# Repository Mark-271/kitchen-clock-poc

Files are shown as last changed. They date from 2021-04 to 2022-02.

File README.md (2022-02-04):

# Kitchen clock
This is the project of the kitchen clock with the following functions:
- date
- alarm
- clock
- 24 hour time format
- thermometer
## Breadboard connection
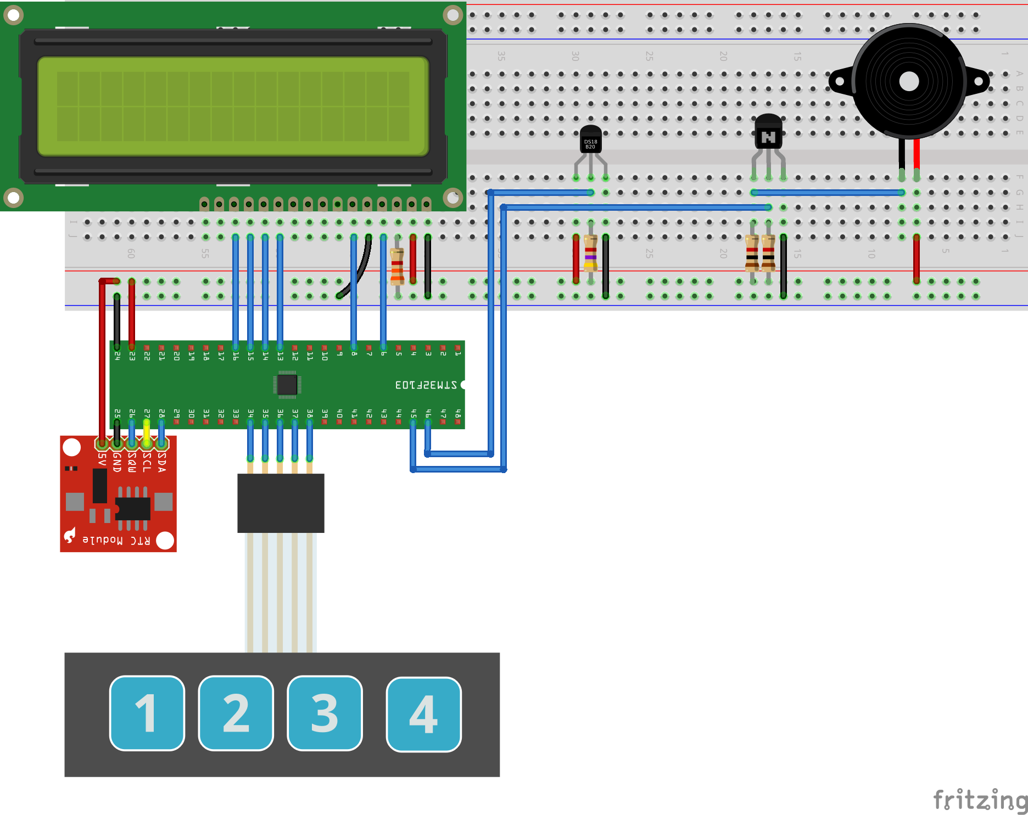
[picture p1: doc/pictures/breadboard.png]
bb

## Electrical wiring diagram
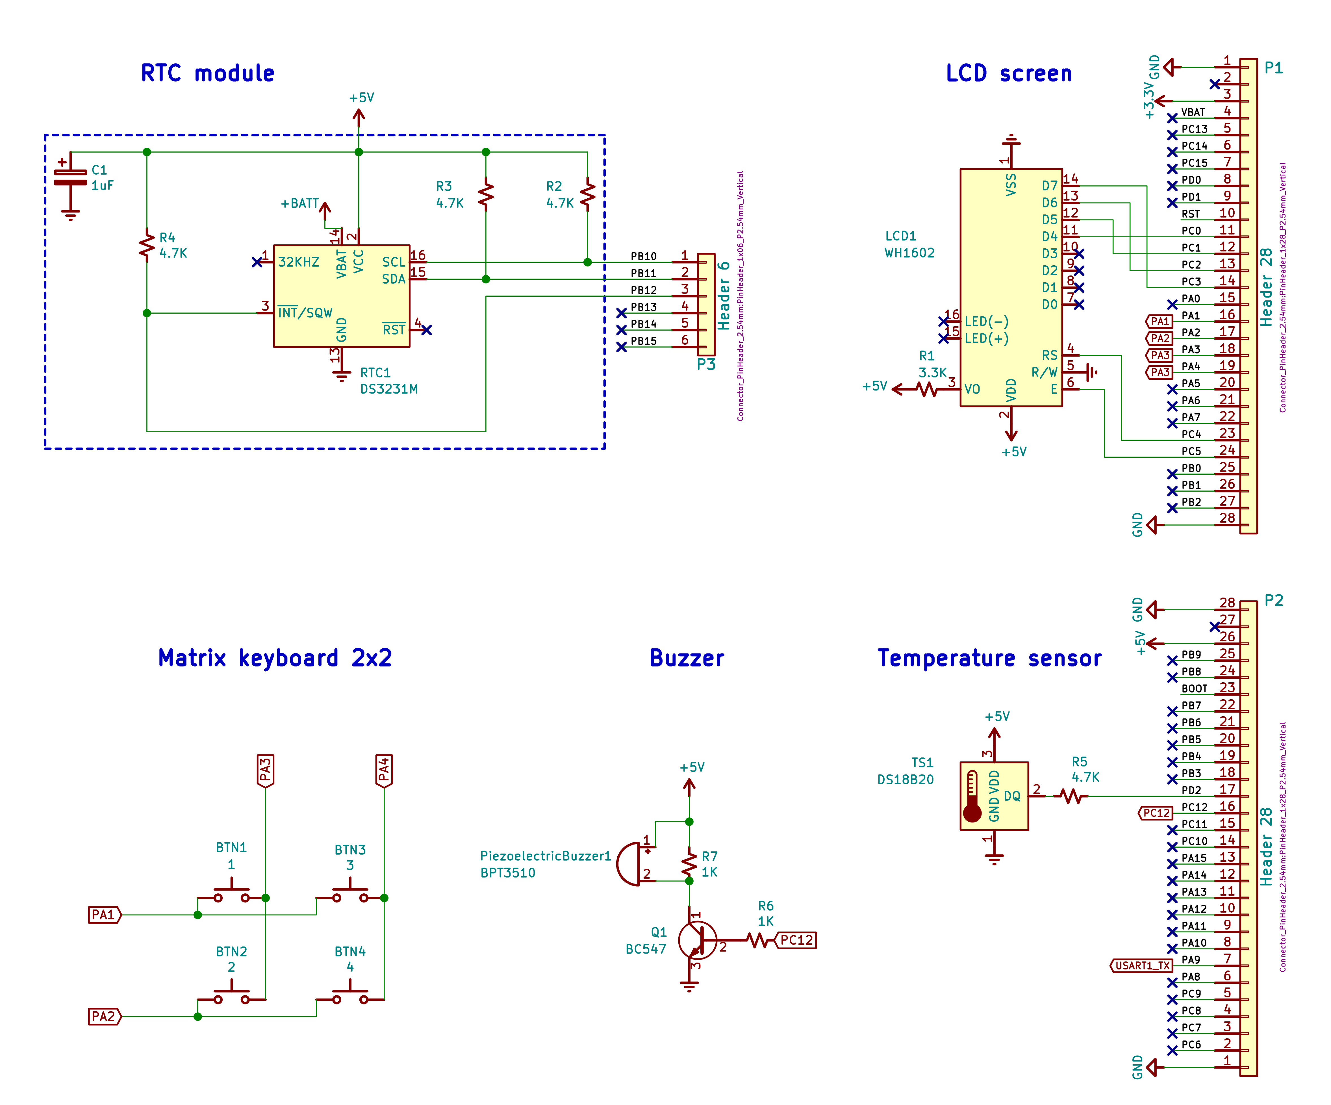
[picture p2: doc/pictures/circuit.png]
scheme

## Used electronic components
- STM32VLDISCOVERY board with the STM32F100RB MCU
- digital thermometer DS18B20
- LCD screen WH1602
- matrix keyboard 2x2
- RTC module DS3231
- piezoelectric buzzer
- resistors:
  - 1 kohm *(x2)*
  - 4.7 kohm *(x1)*
  - 3.3 kohm *(x1)*
- NPN transistor BC547 *(x1)*
- breadboard
- jumper wires
## Building and installing
### Prerequisites
Building requires libopencm3 and an arm-none-eabi toolchain.
The build must be tuned with limited number of parameters in Makefile,
by specifying them as environment variables, for example:
```
export PATH=/opt/gcc-arm-none-eabi-9-2020-q2-update/bin:$PATH
export CROSS_COMPILE=arm-none-eabi-
export OPENCM3_DIR=$HOME/repos/libopencm3
```
- `CROSS_COMPILE` contains `arm-none-eabi-` prefix
- `OPENCM3_DIR` contains path to root directory of
[libopencm3](https://github.com/libopencm3/libopencm3) source tree (must
be built)
### Serial console
Serial communication (used in the project, for example, for debug) is
performed via `minicom` through RS-232 adapter.
*PA9* as the default *USART1_TX* pin is used on the STM32VLDISCOVERY board.

UART configuration:
```
115200 8N1
No flowcontrol
```
### Building
```
$ make
```
### Flashing
For flashing `st-flash` utility is used.
```
$ make flash
```
## Author
**Mark Sungurov <mark.sungurov@gmail.com>**
## License
This project is licensed under the GPLv3.

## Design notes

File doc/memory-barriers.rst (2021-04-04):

Memory barriers
===============

(borrowed from Linux kernel memory-barriers.txt)

Compiler barrier
----------------

The Linux kernel has an explicit compiler barrier function that prevents the
compiler from moving the memory accesses either side of it to the other side::

    barrier();

This is a general barrier -- there are no read-read or write-write
variants of ``barrier()``.  However, ``READ_ONCE()`` and ``WRITE_ONCE()`` can be
thought of as weak forms of ``barrier()`` that affect only the specific
accesses flagged by the ``READ_ONCE()`` or ``WRITE_ONCE()``.

The ``barrier()`` function has the following effects:

* Prevents the compiler from reordering accesses following the
  ``barrier()`` to precede any accesses preceding the ``barrier()``.
  One example use for this property is to ease communication between
  interrupt-handler code and the code that was interrupted.
* Within a loop, forces the compiler to load the variables used
  in that loop's conditional on each pass through that loop.

The ``READ_ONCE()`` and ``WRITE_ONCE()`` functions can prevent any number of
optimizations that, while perfectly safe in single-threaded code, can
be fatal in concurrent code.  Here are some examples of these sorts
of optimizations:

* The compiler is within its rights to reorder loads and stores
  to the same variable, and in some cases, the CPU is within its
  rights to reorder loads to the same variable.  This means that
  the following code:

  .. code-block:: c

      a[0] = x;
      a[1] = x;

  Might result in an older value of x stored in a[1] than in a[0].
  Prevent both the compiler and the CPU from doing this as follows:

  .. code-block:: c

      a[0] = READ_ONCE(x);
      a[1] = READ_ONCE(x);

  In short, ``READ_ONCE()`` and ``WRITE_ONCE()`` provide cache coherence for
  accesses from multiple CPUs to a single variable.

* The compiler is within its rights to merge successive loads from
  the same variable.  Such merging can cause the compiler to "optimize"
  the following code:

  .. code-block:: c

      while (tmp = a)
      do_something_with(tmp);

  into the following code, which, although in some sense legitimate
  for single-threaded code, is almost certainly not what the developer
  intended:

  .. code-block:: c

      if (tmp = a)
          for (;;)
              do_something_with(tmp);

  Use ``READ_ONCE()`` to prevent the compiler from doing this to you:

  .. code-block:: c

      while (tmp = READ_ONCE(a))
          do_something_with(tmp);

* The compiler is within its rights to reload a variable, for example,
  in cases where high register pressure prevents the compiler from
  keeping all data of interest in registers.  The compiler might
  therefore optimize the variable ``tmp`` out of our previous example:

  .. code-block:: c

      while (tmp = a)
          do_something_with(tmp);

  This could result in the following code, which is perfectly safe in
  single-threaded code, but can be fatal in concurrent code:

  .. code-block:: c

      while (a)
          do_something_with(a);

  For example, the optimized version of this code could result in
  passing a zero to ``do_something_with()`` in the case where the variable
  a was modified by some other CPU between the ``while`` statement and
  the call to ``do_something_with()``.

  Again, use ``READ_ONCE()`` to prevent the compiler from doing this:

  .. code-block:: c

      while (tmp = READ_ONCE(a))
          do_something_with(tmp);

  Note that if the compiler runs short of registers, it might save
  ``tmp`` onto the stack.  The overhead of this saving and later restoring
  is why compilers reload variables.  Doing so is perfectly safe for
  single-threaded code, so you need to tell the compiler about cases
  where it is not safe.

* The compiler is within its rights to omit a load entirely if it knows
  what the value will be.  For example, if the compiler can prove that
  the value of variable ``a`` is always zero, it can optimize this code:

  .. code-block:: c

      while (tmp = a)
          do_something_with(tmp);

  Into this:

  .. code-block:: c

      do { } while (0);

  This transformation is a win for single-threaded code because it
  gets rid of a load and a branch.  The problem is that the compiler
  will carry out its proof assuming that the current CPU is the only
  one updating variable ``a``.  If variable ``a`` is shared, then the
  compiler's proof will be erroneous.  Use ``READ_ONCE()`` to tell the
  compiler that it doesn't know as much as it thinks it does:

  .. code-block:: c

      while (tmp = READ_ONCE(a))
          do_something_with(tmp);

  But please note that the compiler is also closely watching what you
  do with the value after the ``READ_ONCE()``.  For example, suppose you
  do the following and ``MAX`` is a preprocessor macro with the value 1:

  .. code-block:: c

      while ((tmp = READ_ONCE(a)) % MAX)
          do_something_with(tmp);

  Then the compiler knows that the result of the ``%`` operator applied
  to ``MAX`` will always be zero, again allowing the compiler to optimize
  the code into near-nonexistence.  (It will still load from the
  variable ``a``.)

* Similarly, the compiler is within its rights to omit a store entirely
  if it knows that the variable already has the value being stored.
  Again, the compiler assumes that the current CPU is the only one
  storing into the variable, which can cause the compiler to do the
  wrong thing for shared variables.  For example, suppose you have
  the following:

  .. code-block:: c

      a = 0;
      ... Code that does not store to variable a ...
      a = 0;

  The compiler sees that the value of variable ``a`` is already zero, so
  it might well omit the second store.  This would come as a fatal
  surprise if some other CPU might have stored to variable ``a`` in the
  meantime.

  Use ``WRITE_ONCE()`` to prevent the compiler from making this sort of
  wrong guess:

  .. code-block:: c

      WRITE_ONCE(a, 0);
      ... Code that does not store to variable a ...
      WRITE_ONCE(a, 0);

* The compiler is within its rights to reorder memory accesses unless
  you tell it not to.  For example, consider the following interaction
  between process-level code and an interrupt handler:

  .. code-block:: c

      void process_level(void)
      {
          msg = get_message();
          flag = true;
      }

       void interrupt_handler(void)
       {
           if (flag)
               process_message(msg);
       }

  There is nothing to prevent the compiler from transforming
  ``process_level()`` to the following, in fact, this might well be a
  win for single-threaded code:

  .. code-block:: c

      void process_level(void)
      {
          flag = true;
          msg = get_message();
      }

  If the interrupt occurs between these two statement, then
  ``interrupt_handler()`` might be passed a garbled ``msg``.  Use
  ``WRITE_ONCE()`` to prevent this as follows:

  .. code-block:: c

      void process_level(void)
      {
          WRITE_ONCE(msg, get_message());
          WRITE_ONCE(flag, true);
      }

      void interrupt_handler(void)
      {
          if (READ_ONCE(flag))
              process_message(READ_ONCE(msg));
      }

  Note that the ``READ_ONCE()`` and ``WRITE_ONCE()`` wrappers in
  ``interrupt_handler()`` are needed if this interrupt handler can itself
  be interrupted by something that also accesses ``flag`` and ``msg``,
  for example, a nested interrupt or an NMI.  Otherwise, ``READ_ONCE()``
  and ``WRITE_ONCE()`` are not needed in ``interrupt_handler()`` other than
  for documentation purposes.  (Note also that nested interrupts
  do not typically occur in modern Linux kernels, in fact, if an
  interrupt handler returns with interrupts enabled, you will get a
  ``WARN_ONCE()`` splat.)

  You should assume that the compiler can move ``READ_ONCE()`` and
  ``WRITE_ONCE()`` past code not containing ``READ_ONCE()``, ``WRITE_ONCE()``,
  ``barrier()``, or similar primitives.

  This effect could also be achieved using ``barrier()``, but ``READ_ONCE()``
  and ``WRITE_ONCE()`` are more selective:  With ``READ_ONCE()`` and
  ``WRITE_ONCE()``, the compiler need only forget the contents of the
  indicated memory locations, while with ``barrier()`` the compiler must
  discard the value of all memory locations that it has currented
  cached in any machine registers.  Of course, the compiler must also
  respect the order in which the ``READ_ONCE()``-s and ``WRITE_ONCE()``-s
  occur, though the CPU of course need not do so.

* The compiler is within its rights to invent stores to a variable,
  as in the following example:

  .. code-block:: c

      if (a)
          b = a;
      else
          b = 42;

  The compiler might save a branch by optimizing this as follows:

  .. code-block:: c

      b = 42;
      if (a)
          b = a;

  In single-threaded code, this is not only safe, but also saves
  a branch.  Unfortunately, in concurrent code, this optimization
  could cause some other CPU to see a spurious value of 42 -- even
  if variable ``a`` was never zero -- when loading variable ``b``.
  Use ``WRITE_ONCE()`` to prevent this as follows:

  .. code-block:: c

      if (a)
          WRITE_ONCE(b, a);
      else
          WRITE_ONCE(b, 42);

  The compiler can also invent loads.  These are usually less
  damaging, but they can result in cache-line bouncing and thus in
  poor performance and scalability.  Use ``READ_ONCE()`` to prevent
  invented loads.

* For aligned memory locations whose size allows them to be accessed
  with a single memory-reference instruction, prevents "load tearing"
  and "store tearing", in which a single large access is replaced by
  multiple smaller accesses.  For example, given an architecture having
  16-bit store instructions with 7-bit immediate fields, the compiler
  might be tempted to use two 16-bit store-immediate instructions to
  implement the following 32-bit store:

  .. code-block:: c

      p = 0x00010002;

  Please note that GCC really does use this sort of optimization,
  which is not surprising given that it would likely take more
  than two instructions to build the constant and then store it.
  This optimization can therefore be a win in single-threaded code.
  In fact, a recent bug (since fixed) caused GCC to incorrectly use
  this optimization in a volatile store.  In the absence of such bugs,
  use of ``WRITE_ONCE()`` prevents store tearing in the following example:

  .. code-block:: c

      WRITE_ONCE(p, 0x00010002);

  Use of packed structures can also result in load and store tearing,
  as in this example:

  .. code-block:: c

      struct __attribute__((__packed__)) foo {
          short a;
          int b;
          short c;
      };
      struct foo foo1, foo2;
      ...

      foo2.a = foo1.a;
      foo2.b = foo1.b;
      foo2.c = foo1.c;

  Because there are no ``READ_ONCE()`` or ``WRITE_ONCE()`` wrappers and no
  ``volatile`` markings, the compiler would be well within its rights to
  implement these three assignment statements as a pair of 32-bit
  loads followed by a pair of 32-bit stores.  This would result in
  load tearing on ``foo1.b`` and store tearing on ``foo2.b``.  ``READ_ONCE()``
  and ``WRITE_ONCE()`` again prevent tearing in this example:

  .. code-block:: c

      foo2.a = foo1.a;
      WRITE_ONCE(foo2.b, READ_ONCE(foo1.b));
      foo2.c = foo1.c;

All that aside, it is never necessary to use ``READ_ONCE()`` and
``WRITE_ONCE()`` on a variable that has been marked ``volatile``.  For example,
because ``jiffies`` is marked ``volatile``, it is never necessary to
say ``READ_ONCE(jiffies)``.  The reason for this is that ``READ_ONCE()`` and
``WRITE_ONCE()`` are implemented as ``volatile`` casts, which has no effect when
its argument is already marked ``volatile``.

Please note that these compiler barriers have no direct effect on the CPU,
which may then reorder things however it wishes (but Cortex-M doesn't do
reordering).

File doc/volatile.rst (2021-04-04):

Do not use "volatile" modifier
==============================

:Author: Sam Protsenko

``volatile`` keyword purpose is to turn off the compiler optimizations for
caching the variable in the register. Very rarely its usage is justified. This
document discusses why its usage should be avoided at all in the firmware code.
It's also discouraged to use ``volatile`` in Linux kernel, see [1]_ for details.

As discussed below, ``volatile`` shouldn't be used at all. Using provided in
the firmware sync API (like ``READ_ONCE()``, ``WRITE_ONCE()``,
``enter_critical()``, ``exit_critical()`` and ``barrier()``) and libopencm3 API
for accessing the memory-mapped registers (like ``MMIO32()``) takes care of
disabling optimizations for us, so that we can avoid using ``volatile`` at all.

Summary
-------

Here is a short cheat sheet on when to use which API:

 * **Never** use ``volatile`` keyword explicitly in your code
 * Use existing API to access hardware registers (like ``MMIO32()``)
 * Use ``READ_ONCE()`` (in mainline code): for accessing global variables that
   change in ISR (to avoid compiler optimizations)
 * Use ``WRITE_ONCE()`` (in ISR code): when changing global variables
   (pairing it with ``READ_ONCE()`` helps compiler to understand variable usage)
 * Use local non-volatile variable to keep ``READ_ONCE()`` result
   (to avoid under-optimization)
 * Use critical sections ( ``enter_critical()``, ``exit_critical()`` ) to
   perform non-atomic operations (Read-Modify-Write, multi-word variable access,
   unaligned access, etc) in mutual-exclusive manner
 * There is no need to use ``READ_ONCE()`` if you are already inside of
   critical section
 * If you need atomic bit operations (bit-wise RMW per once CPU instruction),
   consider using bit-banding mechanism (see ``BBIO_SRAM()`` and
   ``BBIO_PERIPH()`` API in libopencm3)
 * Use ``barrier()`` to avoid compiler reordering of load/store instructions
   (e.g. to keep the order of two sequntial atomic operations)
 * For implementing delay loops: use either ``READ_ONCE()`` for checking
   the condition or just add ``barrier()`` inside the loop. Even better idea is
   to use existing API like ``mdelay()`` or software timers API to implement
   non-blocking sleep.

Details are discussed further.

Using ``volatile`` for ISR modifiable variable
----------------------------------------------

In Embedded world the ``volatile`` is often used for global variables being
modified from ISR. Compiler can't see the access to that variable from ISR, as
ISR is not executed from any other function. Here is an example:

.. code-block:: c

    static int a;

    int main(void)
    {
        while (a == 0) { }
    }

    void some_isr(void)
    {
        a++;
    }

In this case a compiler indeed throws the ``a == 0`` check away, which leads to
infinite loop. And a programmer might have a temptation to add ``volatile``
modifier to ``a`` variable declaration, like this:

.. code-block:: c

    static volatile int a;

    int main(void)
    {
        while (a == 0) { }
    }

    void some_isr(void)
    {
        a++;
    }

It disables optimizations for ``a`` variable, so compiler will produce correct
binary. But it's not recommended to use this approach because:

  * using ``volatile`` in more elaborate cases is very inefficient, as it
    disables optimizations for all accesses to the variable
  * when calling some functions on that variable, functions must also take
    ``volatile`` parameters, which gets ugly very fast; think about implementing
    queue struct and functions and using it on ``volatile`` variable
  * using ``volatile`` doesn't fix reordering of memory operations (which can be
    done by compiler and CPU); though it is guaranteed that accesses to
    ``volatile`` variable will be ordered, compiler still can generate
    out-of-order instructions between ``volatile`` variable and other variables.
    And of course the processor is free to do any reordering anyway.
  * using ``volatile`` doesn't make variable operations atomic

The C Standard mentions::

    If it is necessary to access a nonvolatile object using volatile semantics,
    the technique is to cast the address of the object to the appropriate
    pointer-to-qualified type, then dereference that pointer.

So here is a better way to disable optimizations using ``volatile`` "in place":

.. code-block:: c

    static int a;

    int main(void)
    {
        while (*(volatile int *)&a == 0) { }
    }

    void some_isr(void)
    {
        a++;
    }

Alternatively, you could place a ``barrier()`` call in the loop.

Even better to do the same using ``READ_ONCE()`` / ``WRITE_ONCE()`` macros
(borrowed from kernel), as compiler will order all memory accesses to ``a``
variable (as both accesses are now marked as ``volatile``):

.. code-block:: c

    static int a;

    int main(void)
    {
        while (READ_ONCE(a) == 0) { }
    }

    void some_isr(void)
    {
        WRITE_ONCE(a, a + 1);
    }

.. warning::

    ``READ_ONCE()`` OR ``WRITE_ONCE()`` DO NOT IMPLY A BARRIER!

So if you want to suppress compiler reordering between accesses to ``a`` and
other variables, additional ``barrier()`` call should be used. But be aware of
possible use-case implications! Refer to [2]_ for further details.

If there is a need to do RMW operation (which is not atomic), one should disable
interrupts to achieve the mutual exclusive behavior. ``enter_critical()`` /
``exit_critical()`` API can be used for this. There is an important thing about
calling external functions::

    Compiler is not allowed to reorder code across external function calls.

Mentioned critical section functions are actually macros, but they incorporate
compiler memory barrier code, which makes those macros conform to statement
above. So this takes care of possible optimizations, and ``volatile`` is not
needed in this case. Example:

.. code-block:: c

    static int a;

    int main(void)
    {
        int a_copy;

        do {
            unsigned long flags;

            enter_critical(flags);
            a_copy = a++;
            exit_critical(flags);
        } while (a_copy == 0);
    }

    void some_isr(void)
    {
       a = a + 1;
    }

Using ``volatile`` for accessing the memory-mapped registers
------------------------------------------------------------

This is another actual case where ``volatile`` is needed. When we want to write
some STM32 register, the naiive approach would be to do something like this:

.. code-block:: c

    int main(void)
    {
        unsigned long *reg = (unsigned long *)0x4ae00000;

        while (*reg == 0) { }
    }

Compiler will produce incorrect code, as compiler can't see where 0x4ae00000
changes, so it presumes it doesn't. Correct version of this code would be:

.. code-block:: c

    int main(void)
    {
        volatile unsigned long *reg = (volatile unsigned long *)0x4ae00000;

        while (*reg == 0) { }
    }

Now the correct binary will be produced. And ``volatile`` is probably the only
way to disable compiler's optimization in this case, so we really have to use
it here. But we already have ``MMIO32()`` macro defined in libopencm3 for this:

.. code-block:: c

    #define MMIO32(addr)    (*(volatile uint32_t *)(addr))

and all peripheral registers have corresponding access macros in libopencm3 too.
So again, we don't need to use ``volatile`` in the firmware code for this.

Atomicity and locking; reordering concerns
------------------------------------------

Some people have wrong idea that using ``volatile`` makes the access to the
variable atomic. Of course it's not true. But this is an important concept,
so let's review how to handle it.

Cortex-M3 (ARMv7-M) processor has next features:

  1. Load/store architecture (as it's RISC processor)
  2. Weakly-ordered memory model

Because of (1), variable modification is not atomic. Such operation requires 3
steps: loading from RAM to register, modification, and store from register to
RAM. Corresponding code in C for variable ``int a`` looks like this:

.. code-block:: c

    a++;

And generated assembler code would look something like this:

.. code-block:: none

    ldr r3, [sp, #4]
    add r3, r3, #1
    str r3, [sp, #4]

Compiler can reorder load/store instructions in order to improve code
efficiency, if it doesn't break the logic of code. But because compiler is not
aware of interrupts, it can reorder instructions incorrectly. Example:

.. code-block:: c

    volatile int ready;
    int message[100];

    void foo(int i)
    {
        message[i/10] = 42;
        ready = 1;
    }

    void some_isr(void)
    {
        while (ready != 1);
        // Read message here
    }

Even though ``volatile`` is used, compiler can re-order instructions so that
``ready`` flag is written before ``message``, and if ISR happens in between of
those writes, it'll try to read not written message. Such issue can be solved
using compiler memory barrier, like this:

.. code-block:: c

    volatile int ready;
    int message[100];

    void foo(int i)
    {
        message[i/10] = 42;
        barrier();
        ready = 1;
    }

    void some_isr(void)
    {
        while (ready != 1);
        // Read message here
    }

Of course, critical section (interrupts disabling) can be used too, but it would
be very inefficient comparing to just using ``barrier()``. Please notice that
even if we use ``READ_ONCE()`` / ``WRITE_ONCE()`` API, we still need to use a
barrier here:

.. code-block:: c

    int ready;
    int message[100];

    void foo(int i)
    {
        message[i/10] = 42;
        barrier();
        WRITE_ONCE(ready, 1);
    }

    void some_isr(void)
    {
        while (READ_ONCE(ready) != 1);
        // read message here
    }

Cortex-M doesn't reorder memory instructions internally. From [3]_::

    Implementation: In the Cortex-M processors data transfers are carried out in
    the programmed order.
    ...
    The Cortex-M processors never perform memory accesses out of order compared
    to instruction flow, however, the architecture does not prohibit this in
    future implementations.

So although ARMv7-M has weakly-ordered memory model and allows out-of-order
execution, Cortex-M implementation doesn't reorder instructions. And because
STM32F105 is single-core (Uniprocessor) chip with no cache, we don't need to
worry about processor barriers when working with regular memory.

References
----------

.. [1] https://www.kernel.org/doc/html/latest/process/volatile-considered-harmful.html
.. [2] :doc:`memory-barriers`
.. [3] ARM Application Note 321: "ARM Cortex-M Programming Guide to Memory
       Barrier Instructions"

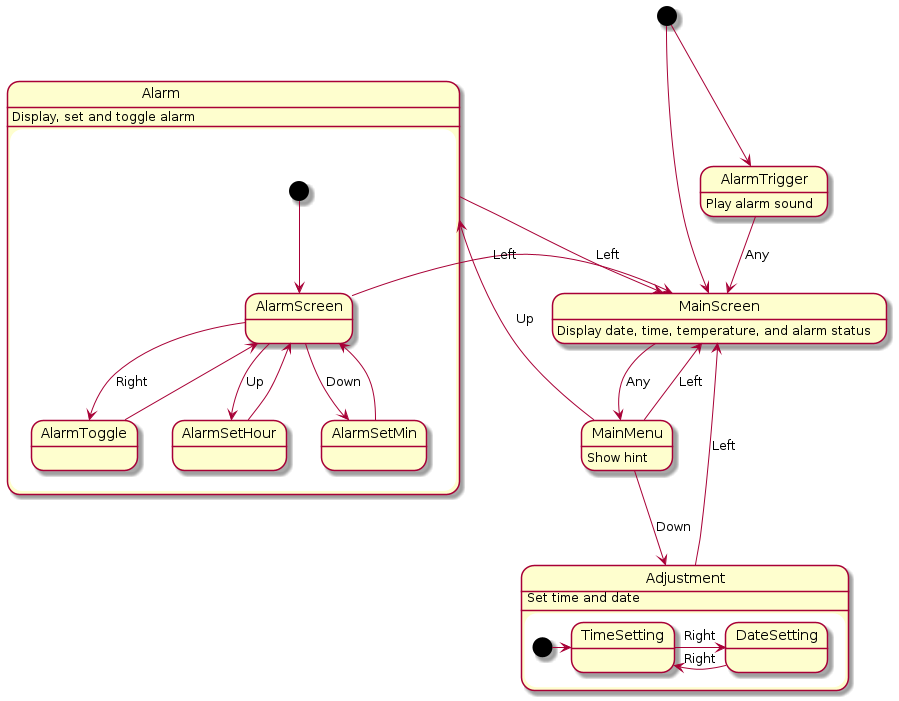
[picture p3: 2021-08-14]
doc/pictures/fsm.png

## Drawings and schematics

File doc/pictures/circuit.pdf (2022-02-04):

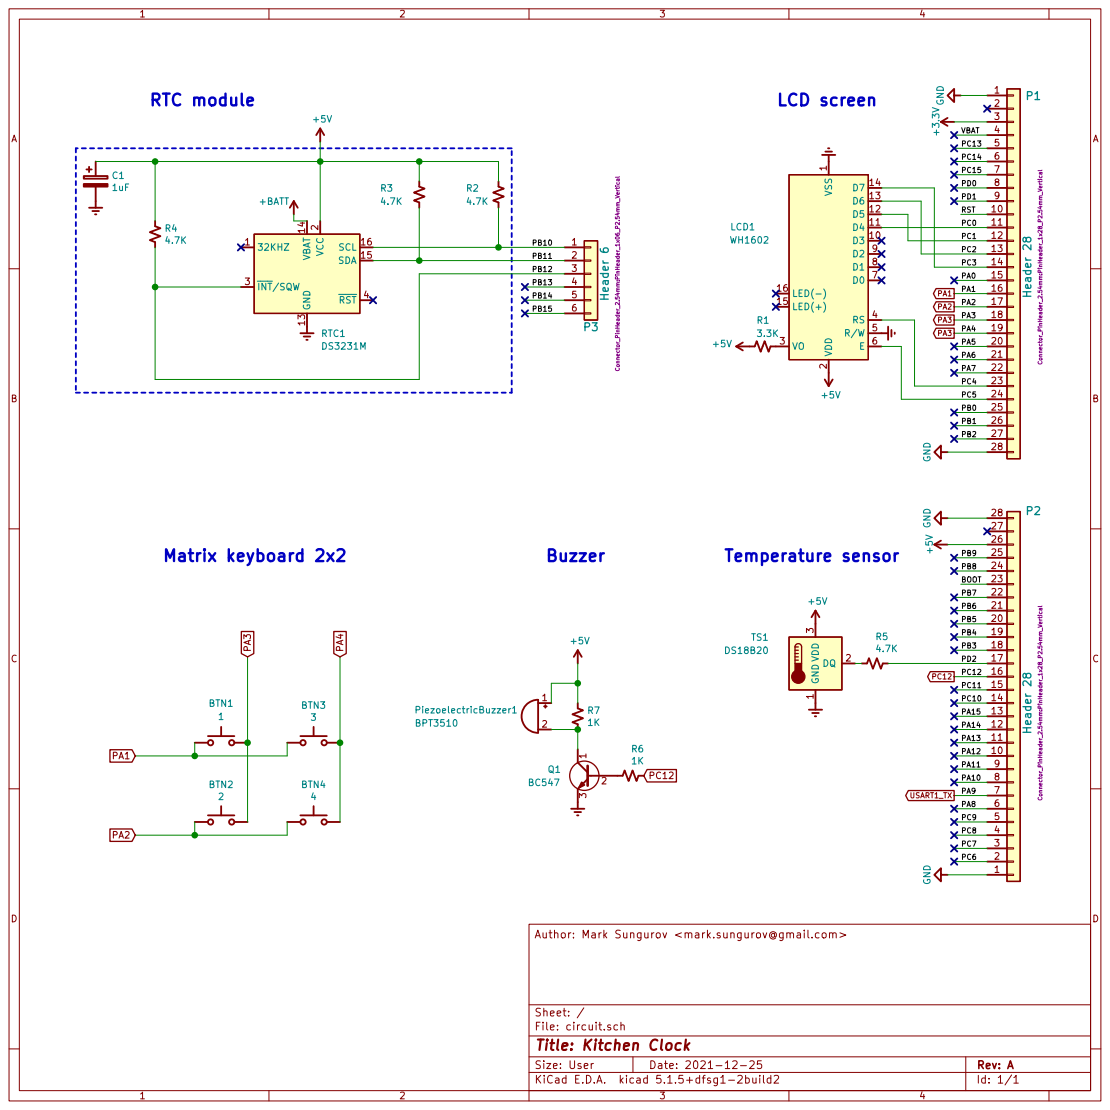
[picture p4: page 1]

File: circuit.sch Sheet: / Author: Mark Sungurov <mark.sungurov@gmail.com>

Id: 1/1 Title: Kitchen Clock

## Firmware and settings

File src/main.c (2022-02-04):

// SPDX-License-Identifier: GPL-3.0-or-later
/*
 * Author: Mark Sungurov <mark.sungurov@gmail.com>
 */

#include <board.h>
#include <core/irq.h>
#include <core/log.h>
#include <core/reset.h>
#include <core/sched.h>
#include <core/swtimer.h>
#include <core/systick.h>
#include <core/wdt.h>
#include <drivers/serial.h>
#include <logic.h>
#include <tools/common.h>
#include <libopencm3/stm32/dbgmcu.h>
#include <stdbool.h>
#include <stddef.h>
#include <stdint.h>
#include <stdio.h>

#ifdef DEBUG
/**
 * Configure clocks behavior in debug build.
 *
 * 1. Do not disable main CPU clock in SLEEP mode (WFI)
 * 2. Disable next timers when CPU core is halted (during debugging):
 *    - watchdog timer (IWDG)
 *    - software timer
 *
 * When using OpenOCD, the DBGMCU_CR register is overwritten with 0x307 value
 * in target/stm32f1x.cfg file, but let's write it here anyway, for another
 * GDB servers like st-util.
 */
static inline void dbg_init(void)
{
	DBGMCU_CR = DBGMCU_CR_SLEEP | DBGMCU_CR_STOP | DBGMCU_CR_STANDBY |
		    DBGMCU_CR_IWDG_STOP | DBGMCU_CR_WWDG_STOP |
		    SWTIMER_TIM_DBGMCU;
}
#else
static inline void dbg_init(void) { }
#endif

static void init_reset(void)
{
	pr_info("Reboot reason: %s\n", reset_cause_name(reset_cause()));
	reset_clear();
}

static void init_core(void)
{
	int err;

	const struct swtimer_hw_tim hw_tim = {
		.base = SWTIMER_TIM_BASE,
		.irq = SWTIMER_TIM_IRQ,
		.rst = SWTIMER_TIM_RST,
		.arr = SWTIMER_TIM_ARR_VAL,
		.psc = SWTIMER_TIM_PSC_VAL,
	};
	struct serial_params serial = {
		.uart = SERIAL_USART,
		.baud = CONFIG_SERIAL_SPEED,
		.bits = 8,
		.stopbits = USART_STOPBITS_1,
		.parity = USART_PARITY_NONE,
		.mode = USART_MODE_TX_RX,
		.flow_control = USART_FLOWCONTROL_NONE
	};

	dbg_init();
	irq_init();

	err = wdt_init();
	if (err) {
		pr_err("Can't initialize watchdog timer: %d\n", err);
		hang();
	}

	err = systick_init();
	if (err) {
		pr_err("Error: Can't initialize systick: %d\n", err);
		hang();
	}

	board_init();
	serial_init(&serial);
	init_reset();
	sched_init();

	err = swtimer_init(&hw_tim);
	if (err) {
		pr_emerg("Error: Can't initialize swtimer\n");
		hang();
	}
}

int main(void)
{
	init_core();
	logic_start();
	sched_start();
}

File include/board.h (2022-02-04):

/* SPDX-License-Identifier: GPL-3.0-or-later */
/*
 * Author: Sam Protsenko <joe.skb7@gmail.com>
 *         Mark Sungurov <mark.sungurov@gmail.com>
 */

#ifndef BOARD_H
#define BOARD_H

#include <libopencm3/cm3/nvic.h>
#include <libopencm3/stm32/exti.h>
#include <libopencm3/stm32/gpio.h>
#include <libopencm3/stm32/i2c.h>
#include <libopencm3/stm32/rcc.h>
#include <libopencm3/stm32/timer.h>
#include <libopencm3/stm32/usart.h>

/* Serial console */
#define SERIAL_GPIO_PORT	GPIOA
#define SERIAL_GPIO_TX_PIN	GPIO_USART1_TX
#define SERIAL_USART		USART1
#define SERIAL_USART_RCC	RCC_USART1
#define SERIAL_GPIO_RCC		RCC_GPIOA

/* Temperature sensor */
#define DS18B20_GPIO_RCC	RCC_GPIOD
#define DS18B20_GPIO_PORT	GPIOD
#define DS18B20_GPIO_PIN	GPIO2

/* LCD display */
#define WH1602_GPIO_RCC		RCC_GPIOC
#define WH1602_GPIO_PORT	GPIOC
#define WH1602_RS_PIN		GPIO4
#define WH1602_EN_PIN		GPIO5
#define WH1602_DB4_PIN		GPIO0
#define WH1602_DB5_PIN		GPIO1
#define WH1602_DB6_PIN		GPIO2
#define WH1602_DB7_PIN		GPIO3

/* Matrix keypad 2x2 */
#define KBD_AFIO_RCC		RCC_AFIO
#define KBD_GPIO_RCC		RCC_GPIOA
#define KBD_GPIO_PORT		GPIOA
#define KBD_GPIO_L1_PIN		GPIO1
#define KBD_GPIO_L2_PIN		GPIO2
#define KBD_GPIO_R1_PIN		GPIO3
#define KBD_GPIO_R2_PIN		GPIO4
#define KBD_EXTI_TRIGGER	EXTI_TRIGGER_BOTH

/* General purpose timer */
#define SWTIMER_TIM_RCC		RCC_TIM2
#define SWTIMER_TIM_BASE	TIM2
#define SWTIMER_TIM_IRQ		NVIC_TIM2_IRQ
#define SWTIMER_TIM_RST		RST_TIM2
#define SWTIMER_TIM_ARR_VAL	19999
#define SWTIMER_TIM_PSC_VAL	5
#define SWTIMER_TIM_DBGMCU	DBGMCU_CR_TIM2_STOP

/* DS3231 RTC */
#define DS3231_DEVICE_ADDR	0x68
#define DS3231_AFIO_RCC		RCC_AFIO
#define DS3231_GPIO_RCC		RCC_GPIOB
#define DS3231_I2C_RCC		RCC_I2C2
#define DS3231_I2C_BASE		I2C2
#define DS3231_I2C_GPIO_PORT	GPIOB
#define DS3231_I2C_SCL_PIN	GPIO10
#define DS3231_I2C_SDA_PIN	GPIO11
#define DS3231_ALARM_PIN	GPIO12
#define DS3231_EXTI_TRIGGER	EXTI_TRIGGER_FALLING
#define DS3231_EXTI_IRQ		NVIC_EXTI15_10_IRQ

/* Buzzer */
#define BUZZER_GPIO_RCC		RCC_GPIOC
#define BUZZER_GPIO_PORT	GPIOC
#define BUZZER_GPIO_PIN		GPIO12

int board_init(void);

#endif /* BOARD_H */

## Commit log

2020-12-11 Add source files for ds18b20 module
    Features which have been incorporated:
    - Structure ow for driver initialization.
    - Prototypes of both ow_init() and ow_exit() functions and their
    definitions.
    - Corresponding updates for src/main.c and Makefile.
2020-12-12 Add functionality to ds18b20 module
    Add write_bit(), ow_write_byte().
    Modify ow_exit().
    Add macros for 1-wire timings.
    Add commands enumeration.
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2020-12-29 Split DS18B20.* into two parts
    Sources one_wire.* are for general 1-wire bus driver.
    Files ds18b20.* are for more specific digital thermometer driver.
2020-12-30 Improve code
    main: Add reverse_replace(), add tempval_to_str().
    common: Remove redundant code.
    [main.c]
2021-01-04 Add unit test for tempval converting function
    test/ Implement test_tempval_to_str(), modify Makefile.
    main: Fixed tempval_to_str().
    ds18b20.h: Fixed ds18b20_get_temperature().
    [main.c]
2021-01-09 wh1602: Return -1 in case of failure
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2021-01-14 Add functionality and fix WH1602 module
    [board.h, main.c, wh1602.c]
2021-01-15 Improve code
    one_wire: Modify ow_init(), ow_reset_pulse(), ow_read_bit().
    Add critical sectin routins to handle possible interrupts.
    main: Add ow_flag to hangle possible failures during ow initialization.
    DS18B20 formatted temperature data are displayed on the screen
    [main.c, one_wire.c]
2021-01-16 wh1602: Big refactoring
    This chunk does next stuff:
    - get rid of global variable
    - extract command write function
    - unify delay units
    - fix GPIO port reading
    - coding style
    - remove redundant LCD screen clearing function
    - provide proper critical sections architecture
    - get rid of magic numbers
    - added required includes to wh1602.h
    - simplified wh1602_set_line() API
    - removed critical section from wh1602_init()
    - split struct wh1602 into obj and config
    - split main() into init() and loop()
    [main.c, wh1602.c]
2021-01-16 serial: Make serial driver a singleton
    And provide some various fixes while at it.
    [main.c]
2021-01-19 one_wire: Code refactoring
    Add comments.
    Clarify parameter names.
    Fix interupt critical section.
    [one_wire.c]
2021-01-19 ds18b20: Code refactoring
    Clarify names.
    Get rid of magic numbers.
    Fix interrupt critical section.
    Transferred tempval_to_str().
    Add tools module
    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
2021-01-21 Add button use case
    main: Implement TIM4 interrupt.
    Add button handling routine.
    board: Add button specific definitions.
    Fix board_init().
    [board.c, board.h, main.c]
2021-01-22 Add keyboard driver sources
    keyboard: Add struct kb, add keyboard_init and keyboard_exit.
    Makefile: Add keyboard obj file, remove button obj.
    board: Add stuff for keyboard module, remove button specific code.
    main: Initialize kb struct.
    Add keyboard_init, remove button_init
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2021-01-25 ds18b20: Code refactoring
    Replace enum cmd with #define constants
    Add prefix CMD_
    DS18b20_H -> DS18B20_H
    Change hex nums to lower case
    Rename functions
    [main.c]
2021-01-25 one_wire: Code refactoring
    one_wire: Remove ow_ow.flag and redundant code.
    Replace enum with #define constants.
    main: Add ds18b20_presence_flag.
    [main.c, one_wire.c]
2021-01-26 one_wire: Fix code
    Get rid of ow_flag;
    Fix delay constants names.
    [main.c, one_wire.c]
2021-01-26 Transfer keypad related stuff
    keypad: Declare extern variables for exti and timer event flags.
    Add init functions for exti and timer.
    Modify both kpd_init, kpd_exit.
    main: Get rif of redundants.
2021-01-30 main: Add flag to check state of ds18b20 module
    If ds18b20 crashes (for example if temperature sensor is fried)
    rest of the program should be able to continue just skipping broken module.
    [main.c]
2021-01-30 keyboard: Rework functionality
    Define constants.
    Add kbd_read(), kbd_read_btn().
    [keyboard.c]
2021-01-30 main: Improve error handling behavior
    [main.c]
2021-02-09 board: Add pull mode for pin configuration
    Provide a way to setup particular pull resistor for pins (up or down).
    Also use it right away to configure intenal pull up resistors for matrix
    keyboard read lines while at it.
2021-02-10 keyboard: Rework the matrix keyboard driver
    [board.c, keyboard.c, main.c]
2021-02-11 keyboard: Add scan line delay
    - Wait till the end of transitive voltage stabilizing process at button press
    due to parasitic capacity that is charging/discharging because of weak internal
    pullup.
    - Remove critical section.
2021-02-11 keyboard: Fix timer
    Extract timer settings to named constants.
    [keyboard.c]
2021-02-11 keyboard: Add check for button state
    - Change exti trigger condition to handle button pressed/released.
    - Modify kbd_task.
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2021-02-12 kbd: Add behavior for released button state
    Modify following functions: kbd_read_btn, kbd_task.
2021-02-12 kbd: Add error handling behavior
    Process possible error during kbd_read_btn() execution.
    [kbd.c]
2021-02-12 kbd: Add exti_disable(), exti_enable()
    Disable exti requests upon execution of kbd_read_btn() to prevent
    call of multiple external interrupts during keyboard lines scanning.
    [kbd.c]
2021-03-02 keyboard: Rework kbd task function
    Find out involved buttons and their state (pressed/released).
    Kbd operates in multy-touch mode only for buttons connected to
    different read lines.
    [kbd.c]
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2021-03-02 kbd: Coding style
    Fix way to setup exti. Clean up.
    [kbd.c]
2021-03-02 Fix system clock frequency
    board: Set clocks.
    common: Fix quantity of CPU cycles to wait for 1 usec.
    [board.c]
2021-03-02 kbd: Fix wrong EXTI reset in ISR
    [kbd.c]
2021-03-02 Get rid of hardcoded stuff related to exti
    board: Add exti constants.
    kbd: Get rid of redundant code, modify struct kbd_gpio.
    main: Initialize kbd_gpio obj.
2021-03-02 Fix timer for kbd
    [board.c, board.h, kbd.c]
2021-03-02 kbd: Modify exti initialization routine
    - Rework function for mapping extis to gpios
    - Get rid of magic numbers.
    - Rework function kbd_gpio2irq.
    [board.h, kbd.c, main.c]
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2021-03-02 main: Fix IRQ manager init order
    IRQ manager must be initialized very early, so that any driver
    requesting IRQ will be handled properly.
    [main.c]
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2021-03-02 drivers: one_wire: Don't try to handle bus disruption
    But keep last delay, as it's needed by 1-wire spec.
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2021-03-04 drivers: kbd: Add swtimer for keyboard
    Rename kbd_task -> kbd_handle_btn.
    Register swtimer.
    Remove obselete code.
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2021-03-04 main: Fix displaying temperature on lcd
    [main.c]
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2021-03-13 drivers: kbd: Fix comment for kbd_init
    [kbd.c]
2021-03-13 main: Add error number for ds18b20_init error handling code
    [main.c]
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2021-03-28 drivers: rtc: Add RTC module sources
    Add structures for rtc object.
    Add functions: rtc_init, rtc_exit.
    Modify Makefile.
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2021-03-28 main: Testing RTC module
    Initialize rtc, register sw timer. Get seconds from rtc internal register
    and print obtained data to console.
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2021-03-28 drivers: rtc: Add rtc_get_date()
    Change struct tm.
    Implement rtc_get_date
    Remove excess and obsolete code.
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2021-03-28 drivers: i2c: Fix function i2c_send_start_addr_poll
    Disable EV8_1 (TxE == 1) event after address clearing during master receiving
    transfer sequence.
    [i2c.c]
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2021-03-30 drivers: rtc: Add function rtc_read_date
    Rename (rtc_get_date -> rtc_read_date) and rework it.
    [main.c]
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2021-03-31 drivers: rtc: Rework architecture
    [board.h, main.c]
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2021-04-04 drivers: rtc: Rework rtc_exit()
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2021-04-04 drivers: rtc: Rework "read" functions
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2021-04-04 drivers: kbd: Fix timer
    Timer must be triggered only with exti.
    [kbd.c]
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2021-04-10 Rework ds3231 driver module
    - Rename sources.
    - Rename prefixes rtc to ds3231.
    - Modify makefile, main.c.
    - Add structure repeating enternal registers arrangement.
    - Modify rtc_tm structure to be fully compatible with tm struct from
    time.h.
    - Remove obsolete code.
    [ds3231.c, main.c]
2021-04-10 drivers: ds3231: Add functions to read/write data
    - Add helper RTC helper functions.
    - Add function to read data from ds3231 registers.
    - Add function to set time/date to ds3231 registers.
2021-04-15 drivers: ds3231: Rework driver architecture
    It is not singleton object anymore.
    [ds3231.c, main.c]
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2021-05-16 drivers: kbd: Fix incorrect irq flag cleanup
    exti_reset_request() takes exti number, but nvic number was passed
    instead, which led to unhandled irq, creating infinite ISR call.
    [kbd.c]
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2021-05-23 Makefile: Generate bin file on "make"
    It might be useful to have .bin file around for tinkering. Generate it
    when user runs "make", as doing "make flash" just to get it may be
    tiresome.
2021-05-23 drivers: serial: Move _write() forward declaration to C file
    We don't really want to expose _write() function as a part of serial
    console API.
2021-05-23 core: log: Add logging system implementation
    Basic logging system which allows one to select logging level, so that
    only messages with level less than CONFIG_LOGLEVEL will be printed.
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2021-05-28 drivers: ds3231: Rework function to convert tm data into string
    Usage of funtions from C Standart lib such as strftime() is not
    appropriate due to multiply malloc() calls, which ead to firmware
    stretching,
    [ds3231.c, logic.c]
2021-06-02 core: swtimer: Implement singly linked list for sw timers storage
    It is good practice to use linked list data structure against array
    because of rational memory usage.
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2021-06-21 drivers: buzzer: Configure board file
    [board.c, board.h]
2021-06-27 drivers: buzzer: Add sources
    [buzzer.c, logic.c]
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2021-08-12 drivers: ds3231: Fix ds3231_read_time()
    This is dummy fix. The problem was during the very first reading RTC internal
    registers were storing trash data.
    [ds3231.c]
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2021-08-12 drivers: ds32321: Fixed RTC module
    Module shouldn't hang when alarm is turned on/off. For now proper data
    are written inside DS3231 registers to control alarm configuration.
    [ds3231.c]
2021-08-12 drivers: kbd: Set interrupt priority for user interrupts
    Exti interrupts should have higher priority than tim.
2021-08-12 drivers:ds3231: Rework function ds3231_sel_alarm()
    [ds3231.c]
2021-08-12 drivers:ds3231: Fix function ds3231_set_alarm()
    Data should be written to alarm 1 offset register
    [ds3231.c]
2021-08-12 drivers: ds3231: Modify function ds3231_init()
    For now callback is registered via ds3231_init function
2021-08-14 Update documents
    Add electrical circuit of kitchen watch and Moore state machine to
    describe business logic
2021-08-17 treewide: Correct doxygen comments
    [one_wire.c, wh1602.c]
2021-09-04 core: reset: Integrate module for detecting the reboot reason
    It will be needed to check if reboot happens due to watchdog timer.
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2021-09-04 board: Init ds18b20 pin as "High" by default
    Avoid implicit "reset pulse" on DS18B20 chip by setting its open-drain
    pin to "High" state by default.
    [board.c]
2021-09-04 drivers: one_wire: Handle possible ongoing "reset pulse" on init
    1-wire pin might be configured as "0" on MCU init. In this case the
    reset pulse condition will be happening prior to ow_init(). As ow_init()
    tries to perform its own reset pulse, that might lead to race condition,
    thus breaking the presence pulse expected timing, which in turn leads to
    error during ow_init().
    Handle possible ongoing "presence pulse" by waiting for it to finish,
    before starting to perform presence pulse in ow_init().
    [one_wire.c]
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2021-09-04 main: Print reboot reason on startup
    This might be helpful for debugging, e.g. checking the watchdog timer
    reset, which will be implemented soon.
    [main.c]
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2021-09-04 core: wdt: Set up watchdog timer
    Enable wdt, which is reset by the only periodic task in the project - in
    swtimer_task.
    [main.c]
2021-09-05 main: Fix the reset source notification
    Reset flags in CSR register after system reset should be cleared by
    user.
    While at it, extract reset functionality to the separate function.
    [main.c]
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2021-09-10 logic: Keep device functional when RTC is broken
    [logic.c]
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2021-09-13 drivers: systick: Get rid of volatile keyword
    Do not use "volatile" when accessing or changing global variable in ISR.
    Make use of "READ_ONCE()" and "WRITE_ONCE()" instead.
2021-09-13 logic: Fix misbehavior on nonexisting transition function call
    Pragram should keep working when event on pressing an unused button occures.
    [logic.c]
2021-09-13 core: systick: Module refactoring
    It is a bit obfuscating to treat systick module as the ordinary device
    driver.
2022-02-04 logic: Improve energy efficiency of the device
    Date and time should be updated on the screen only if the "current" and
    "previous" data are different.
2022-02-04 logic: Fix registered swtimer callback function
    For now data displayed on LCD are handled properly, e.i., when new data
    arrives, it must be shown instead of previously stored.
    [logic.c]
2022-02-04 drivers: ds3231: Fix data transform from device registers
    Repair incorrect conversion of data on month of the year contained in
    corresponding timekeeping register of the device
    [ds3231.c]
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2022-02-04 drivers: ds3231: Rework ds3231_task()
    Add preliminary sampling of ds3231 control/status register before
    modifying.
    Properly disable alarm.
    [ds3231.c]
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2022-02-04 drivers: ds3231: Fix bug when single byte transfer fails on i2c
    Solution is to use the appropriate function for it.
    [ds3231.c]
2022-02-04 main: Rework unit test for systick module
    [main.c]
2022-02-04 drivers: ds3231: Fix bug of squared wave output state
    The match between time-keeping registers and alarm registers should
    activate only interrupt enable signal.
    [ds3231.c]
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2022-02-04 logic: Fix bug when alarm switch on/off caused an error
    Error prone behaviour occured during converting to bcd format the data stored
    inside alarm rtc_time structure. Solution is to predefine the value of
    tm_year.
    [logic.c]
2022-02-04 drivers: ds3231: Fix comment to function
    [ds3231.c]
2022-02-04 Relocate melody module
    Sources containing melody to play when alarm goes off must be relocated as they
    do not belong to drivers.
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2022-02-04 drivers: ds3231: Rework ds3231_task()
    [ds3231.c]
2022-02-04 drivers: ds3231: Fix comment to function ds3231_toggle_alarm()
    [ds3231.c]
2022-02-04 drivers: ds3231: Fix comment for ds3231_set_alarm()
    [ds3231.c]
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2022-02-04 core: swtimer: Fix bug of immediate timer expiration on the first run
    As the new prescaler ratio is taken into account at the next update event, the
    update generation event (set UG bit in TIMx_EGR register) should be
    forced before enabling the counter.
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2022-02-04 drivers: ds3231: Fix bug of an extra alarm triggering
    When external interupt triggers, corresponding bit of EXTI_PR register should
    be cleared in exti_isr() function to reset request, otherwise interrupts
    will come constantly.
    [ds3231.c]
2022-02-04 doc: Update docs
    [circuit.kicad_pcb, circuit.sch, kitchen_watch.fzz]
2022-02-04 tools: melody: Module refactoring
    Add timeout to play music for registered period of time as well as short delay
    between replay.
    [logic.c]
2022-02-04 logic: Rework alarm logic according to the user experience approach
    [logic.c]
2022-02-04 Rework logic laying in the base of melody reproducing
    tools: melody: Provide more relevant API, no odds are needed.
    logic: Handle the duration of the melody reproduction.
    [logic.c]
2022-02-04 doc: Update schemes
    [circuit.sch, kitchen_watch.fzz]
2022-02-04 Logic: Handle alarm ringtone playback
    The melody plays only a few times and correctly interrupts when the
    corresponding buttons are pushed.
    [logic.c]
2022-02-04 drivers: buzzer: Rename API functions for better consistency
    [buzzer.c]
2022-02-04 tools: melody: Rework module
    Leave only the melody implementation itself, since another module (player)
    should be responsible for its playing. Implement clear way to store data
    including the case when there is a need to add more melodies.
    [logic.c]
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2022-02-04 logic: Rework logic for alarm triggering
    Add player to play melody when alarm is being triggered. On the one hand melody
    plays for 1 minute and stops. On the other it's being interrupted when any
    button is pushed.
    [logic.c]
2022-02-04 drivers: buzzer: Disable GPIO when note playback is finished
    [buzzer.c]
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2022-02-04 drivers: player: Get rid of stop callback
    Now GPIO line is set to 0 in buzzer driver.
    [logic.c]
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2022-02-04 drivers: player: Fix player object doc in doxy comments
2022-02-04 player: Replace module from drivers as it is not device
    [logic.c]
2022-02-04 logic: Handle possible erroneous case during buzzer initialization
    [logic.c]
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2022-02-04 drivers: buzzer: Change the prefixes in function names
    [buzzer.c, logic.c]
2022-02-04 drivers: buzzer: Rename a structure containing buzzer data
    [buzzer.c, logic.c]
2022-02-04 drivers: buzzer: Implement buzzer_exit() function properly
    [buzzer.c]
2022-02-04 drivers: buzzer: Remove critical section
    Critical sections should always be as fast as possible, otherwise
    it breakes deterministic behavior of interrupts.
    [buzzer.c]
2022-02-04 board: Rename prefix for buzzer specific constants
    [board.c, board.h, logic.c]
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2022-02-04 drivers: kbd: Fix function name
    [kbd.c]
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
